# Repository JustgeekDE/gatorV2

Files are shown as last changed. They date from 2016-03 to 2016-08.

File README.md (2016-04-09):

# Gator
Gator started as a small project to built a set of multipurpose, breadboard friendly TTL gates. It has since morphed into the endeavour to create a complete CPU built out of only discrete NPN transistors, resistors and capacitors.  
It also serves as a test bed for a few techniques to improve the hardware development process.

A 1-Bit full adder
(Above is a 1-bit full adder)

## Errata
- The current instruction set is missing any way to read a memory address from a register. This makes pointers, array iterations and linked list impossible or at least very hard.

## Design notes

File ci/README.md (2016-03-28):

# gator

A continuous delivery pipeline for FIXME

## Usage

* `lein run` will start your pipeline with a web-ui listening on port 8080

## Files

* `/`
    * `project.clj` contains dependencies and build configuration for Leiningen

* `/src/gator/`
    * `pipeline.clj` contains your pipeline-definition
    * `steps.clj` contains your custom build-steps
    * `core.clj` contains the `main` function that wires everything together

* `/resources/`
    * `logback.xml` contains a sample log configuration

## References

* for a more detailed example, look at the [example pipeline](https://github.com/flosell/lambdacd/tree/master/src/todopipeline) in the main LambdaCD project

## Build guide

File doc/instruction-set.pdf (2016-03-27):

# Fistful instruction set

## Word length and bus width

The native word length and memory bus width of the fistful CPU is 12-bit. There is no distinction between registers and other memory, all 4096 12-bit address are directly accessible.
Register 4095 is the program counter (PC) and will be automatically incremented after each instruction has been processed.

## Instruction set

Every instruction is a fixed 32-bit wide. The output is always stored in the first operand. The second operand can be either a register address, an immediate value or be ignored (in case of the identity and invert instructions).
The output of the compare operation will always be either 0x000 or 0xFFF.
All instructions can be made conditional through the first 3 bits of the instruction.
Jumps and conditional jumps can be executed by adding or subtracting from the program counter (register 4095) directly. However the program counter will be incremented by one after the instruction, this needs to be accounted for in the jump instruction.

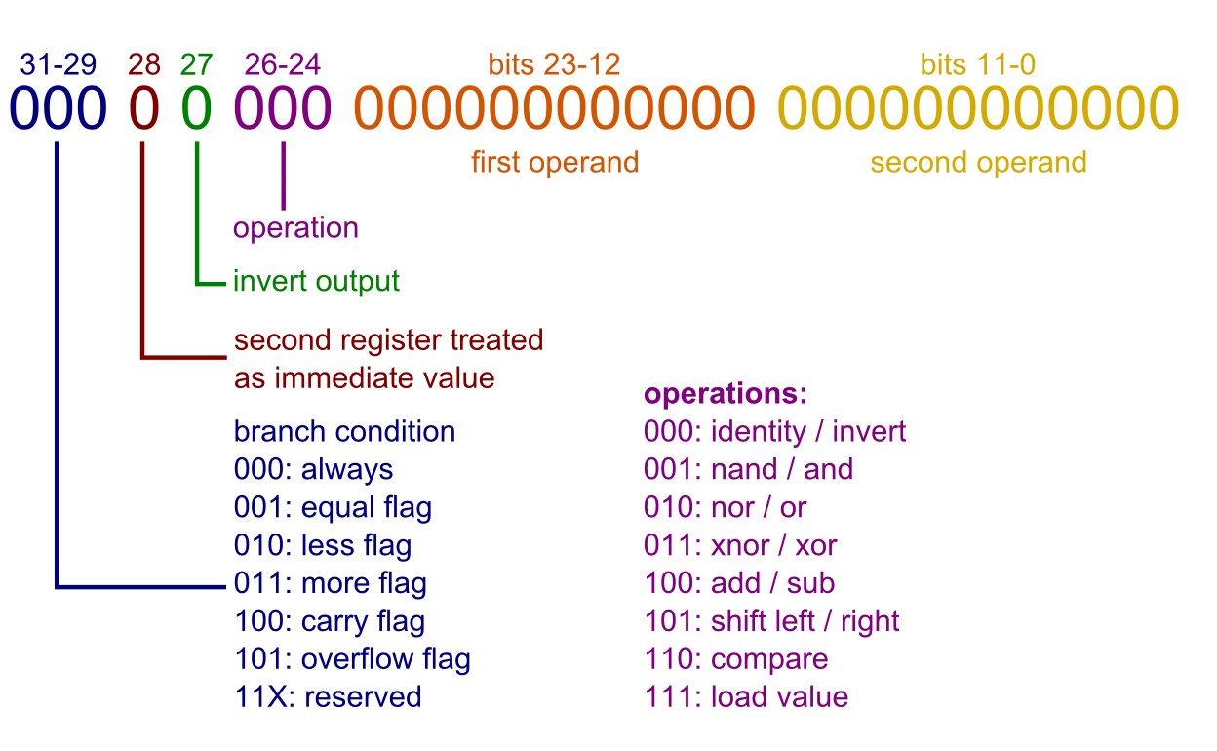
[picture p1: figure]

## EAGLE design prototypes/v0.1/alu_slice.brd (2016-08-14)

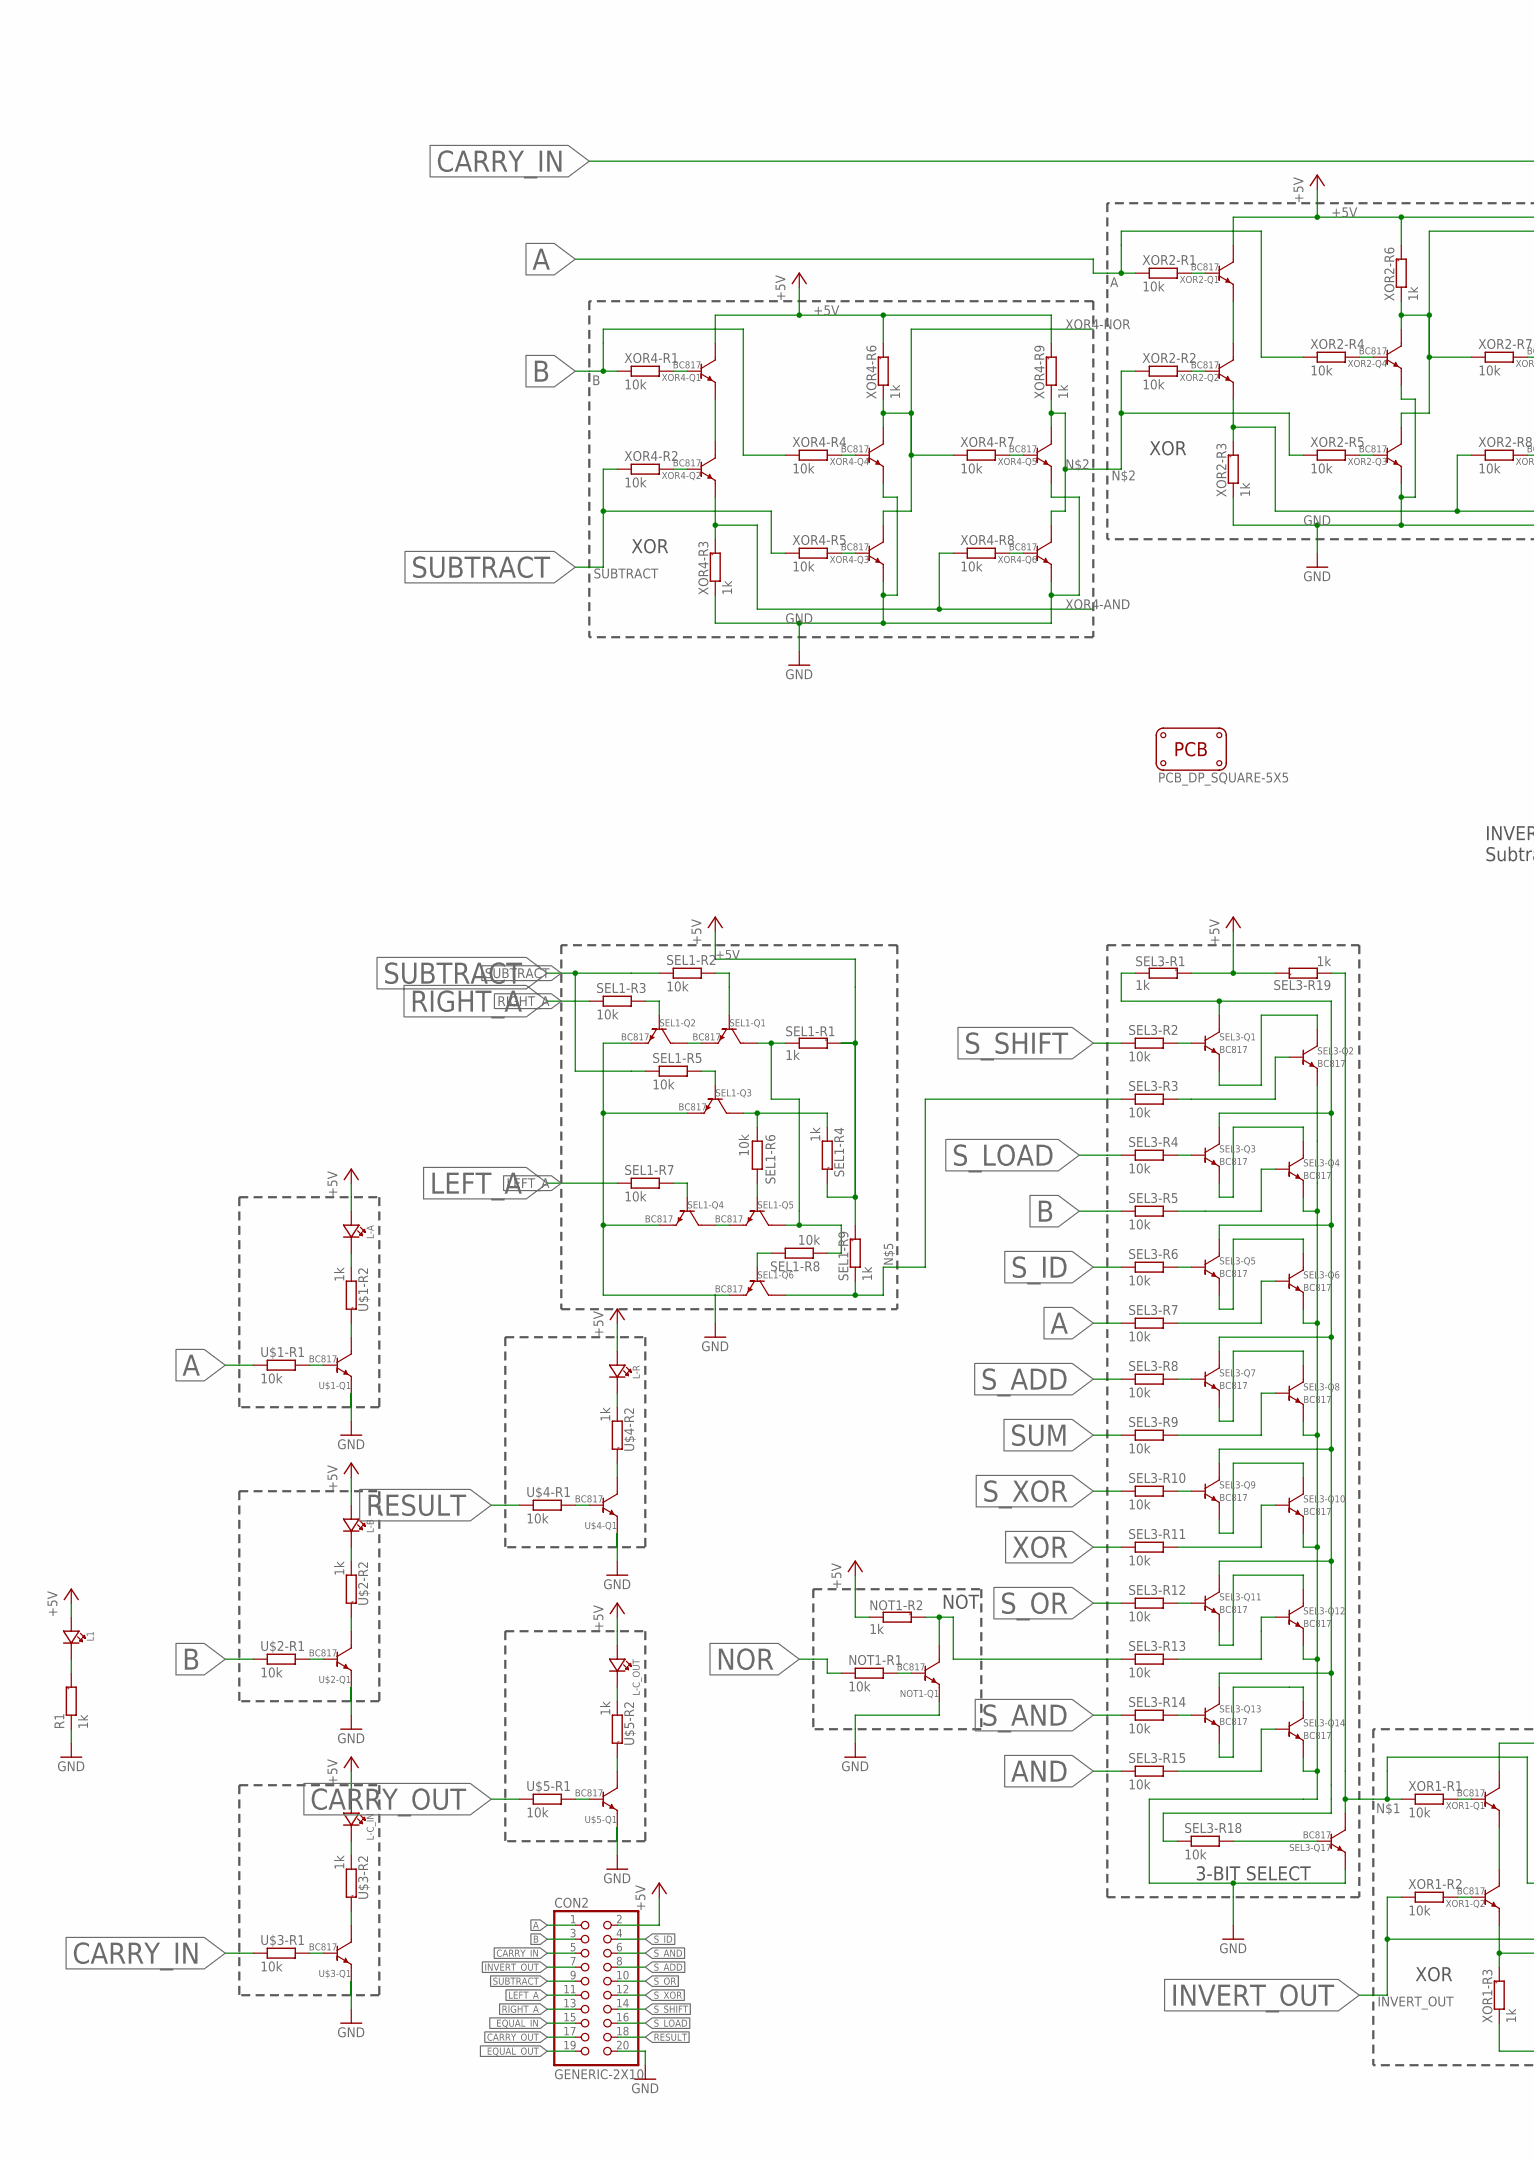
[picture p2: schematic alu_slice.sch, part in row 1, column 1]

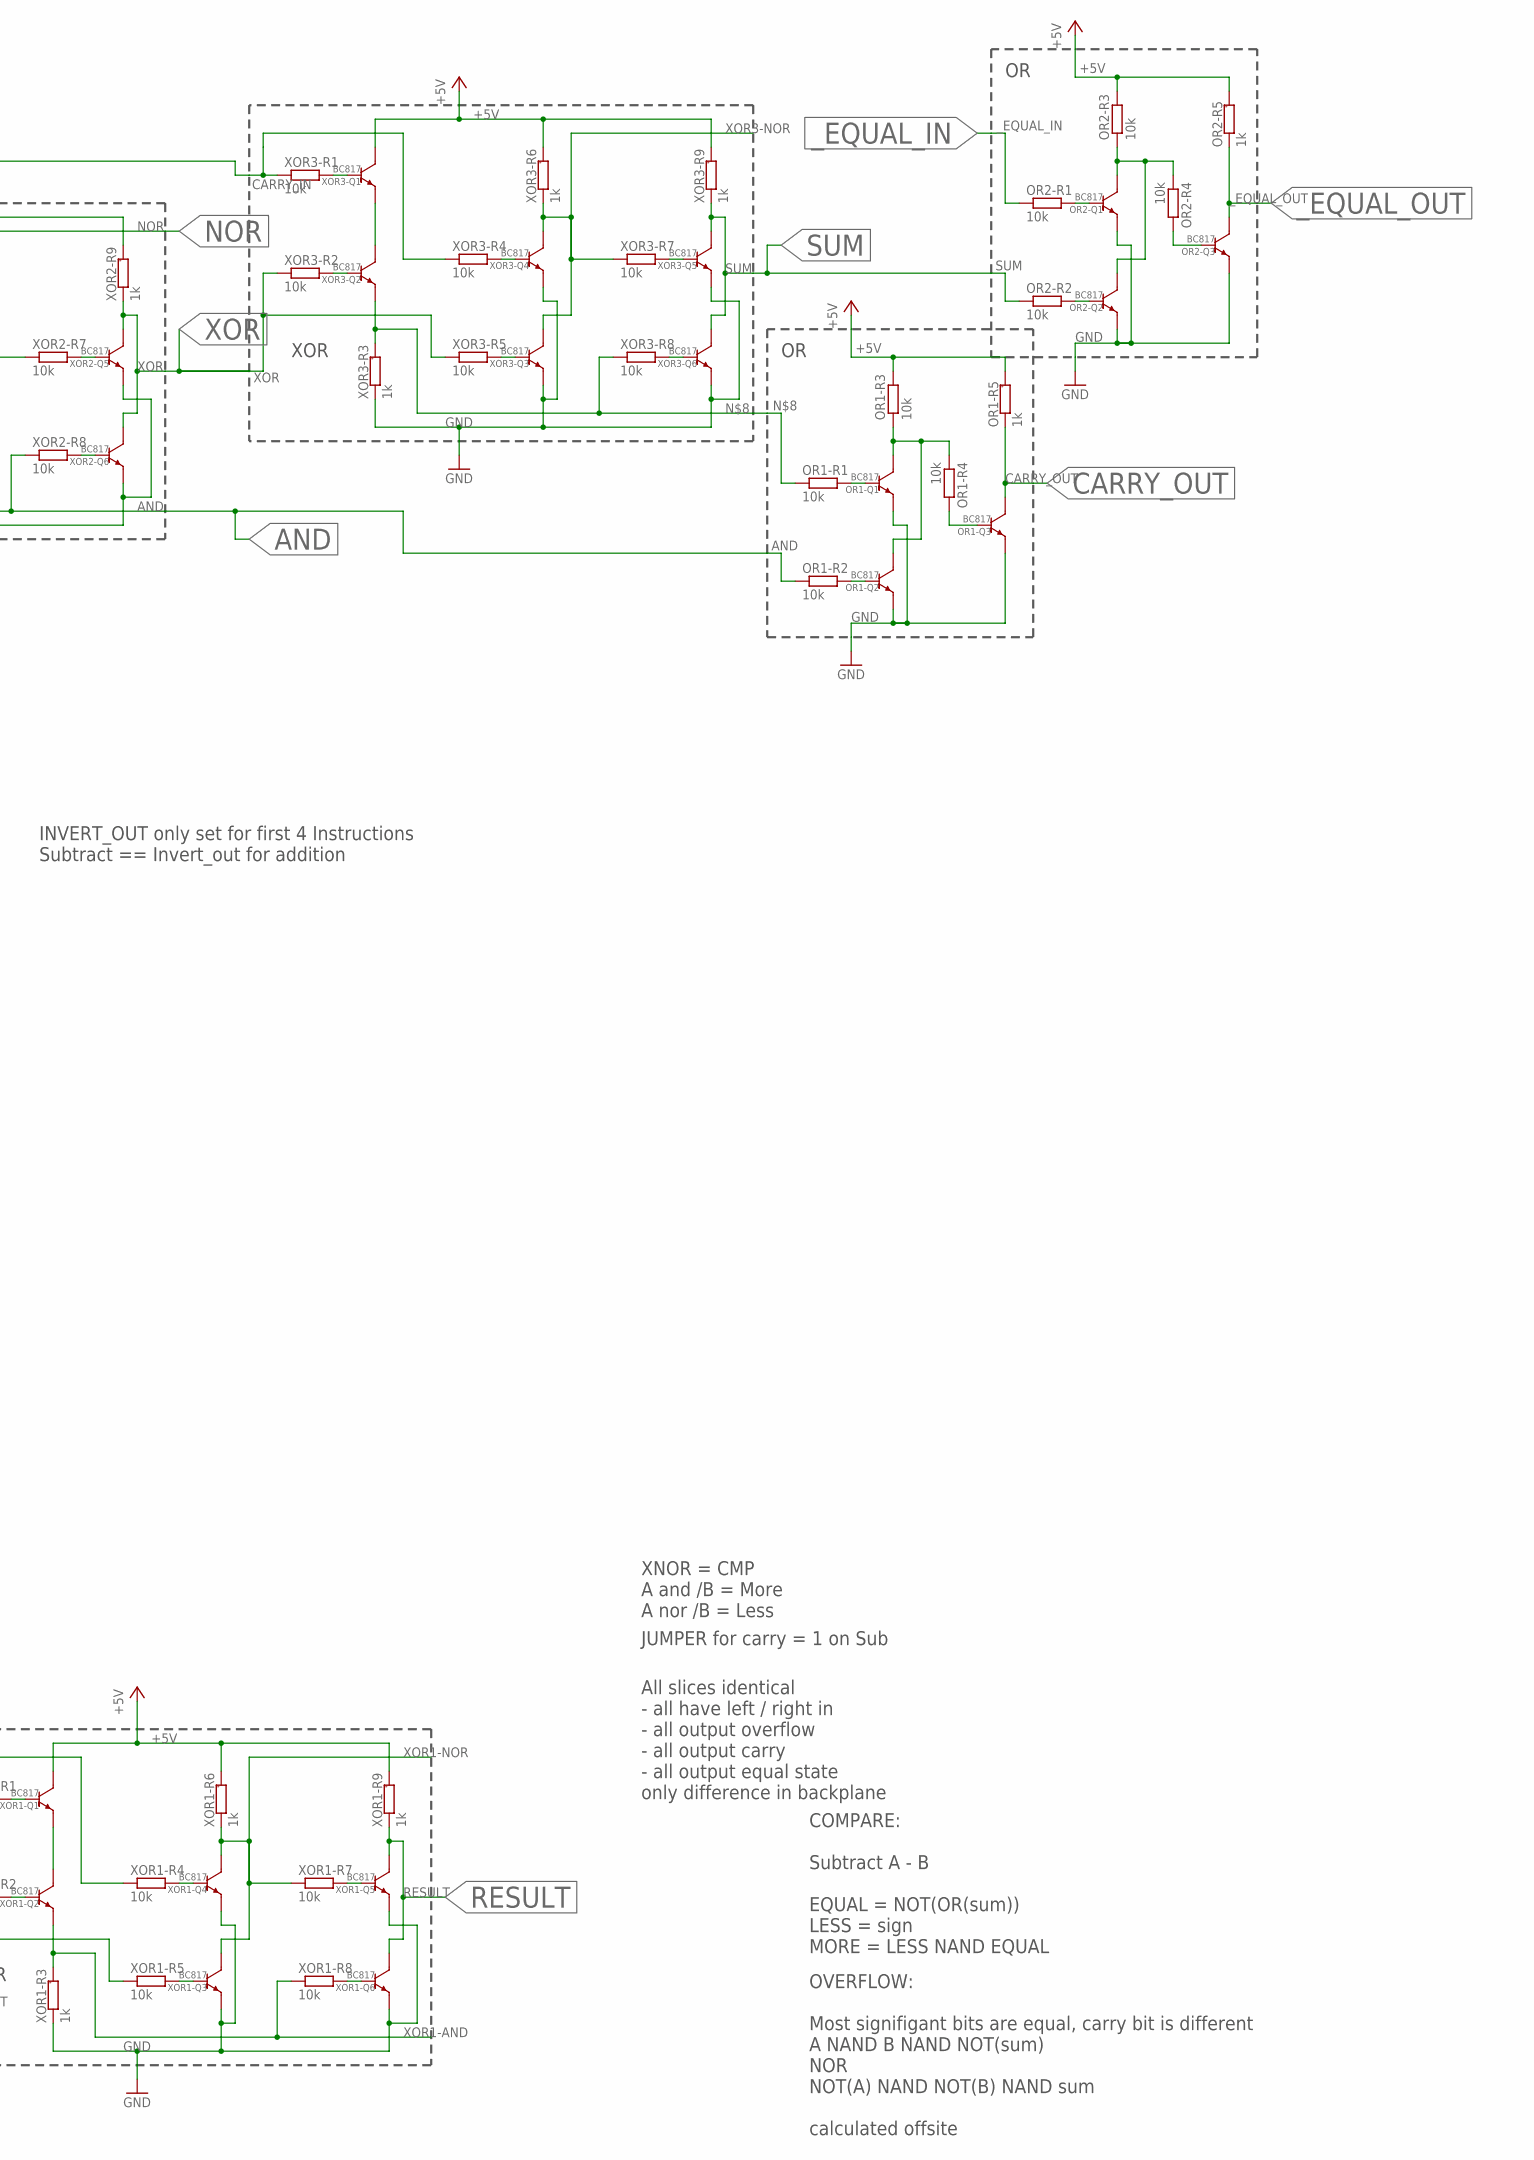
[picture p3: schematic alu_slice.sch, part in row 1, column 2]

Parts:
CON2: GENERIC-2X10; PINHEADER-100MIL-2X10-EDGE
L1: LED0805; CHIPLED_0805
L-A: LED0603; CHIPLED_0603
L-B: LED0603; CHIPLED_0603
L-C_IN: LED0603; CHIPLED_0603
L-C_OUT: LED0603; CHIPLED_0603
L-R: LED0603; CHIPLED_0603
NOT1-Q1: BC817; SOT23
NOT1-R1: 10k; R0603
NOT1-R2: 1k; R0603-MARK
OR1-Q1, OR1-Q2, OR1-Q3, OR2-Q1, OR2-Q2, OR2-Q3: BC817; SOT23
OR1-R1, OR1-R2, OR1-R3, OR1-R4, OR2-R1, OR2-R2, OR2-R3, OR2-R4: 10k; R0603
OR1-R5, OR2-R5: 1k; R0603-MARK
PCB1: PCB_DP_SQUARE-5X5; DP5050_V1
R1: 1k; R0603-MARK
SEL1-Q1, SEL1-Q2, SEL1-Q3, SEL1-Q4, SEL1-Q5, SEL1-Q6, SEL3-Q1, SEL3-Q2, SEL3-Q3, SEL3-Q4, SEL3-Q5, SEL3-Q6, SEL3-Q7, SEL3-Q8, SEL3-Q9, SEL3-Q10, SEL3-Q11, SEL3-Q12, SEL3-Q13, SEL3-Q14, SEL3-Q17: BC817; SOT23
SEL1-R1, SEL1-R4, SEL1-R9, SEL3-R1, SEL3-R19: 1k; R0603-MARK
SEL1-R2, SEL1-R3, SEL1-R5, SEL1-R6, SEL1-R7, SEL1-R8, SEL3-R2, SEL3-R3, SEL3-R4, SEL3-R5, SEL3-R6, SEL3-R7, SEL3-R8, SEL3-R9, SEL3-R10, SEL3-R11, SEL3-R12, SEL3-R13, SEL3-R14, SEL3-R15, SEL3-R18: 10k; R0603
U$1-Q1, U$2-Q1, U$3-Q1, U$4-Q1, U$5-Q1: BC817; SOT23
U$1-R1, U$2-R1, U$3-R1, U$4-R1, U$5-R1: 10k; R0603
U$1-R2, U$2-R2, U$3-R2, U$4-R2, U$5-R2: 1k; R0603-MARK
XOR1-Q1, XOR1-Q2, XOR1-Q3, XOR1-Q4, XOR1-Q5, XOR1-Q6, XOR2-Q1, XOR2-Q2, XOR2-Q3, XOR2-Q4, XOR2-Q5, XOR2-Q6, XOR3-Q1, XOR3-Q2, XOR3-Q3, XOR3-Q4, XOR3-Q5, XOR3-Q6, XOR4-Q1, XOR4-Q2, XOR4-Q3, XOR4-Q4, XOR4-Q5, XOR4-Q6: BC817; SOT23
XOR1-R1, XOR1-R2, XOR1-R4, XOR1-R5, XOR1-R7, XOR1-R8, XOR2-R1, XOR2-R2, XOR2-R4, XOR2-R5, XOR2-R7, XOR2-R8, XOR3-R1, XOR3-R2, XOR3-R4, XOR3-R5, XOR3-R7, XOR3-R8, XOR4-R1, XOR4-R2, XOR4-R4, XOR4-R5, XOR4-R7, XOR4-R8: 10k; R0603
XOR1-R3, XOR1-R6, XOR1-R9, XOR2-R3, XOR2-R6, XOR2-R9, XOR3-R3, XOR3-R6, XOR3-R9, XOR4-R3, XOR4-R6, XOR4-R9: 1k; R0603-MARK

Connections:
+5V: CON2.2, L1.A, L-A.A, L-B.A, L-C_IN.A, L-C_OUT.A, L-R.A, NOT1-R2.1, OR1-R3.2, OR1-R5.2, OR2-R3.2, OR2-R5.2, SEL1-R1.2, SEL1-R4.2, SEL1-R9.2, SEL3-R1.2, SEL3-R19.2, XOR1-Q1.P$3 (COLLECTOR), XOR1-R6.2, XOR1-R9.2, XOR2-Q1.P$3 (COLLECTOR), XOR2-R6.2, XOR2-R9.2, XOR3-Q1.P$3 (COLLECTOR), XOR3-R6.2, XOR3-R9.2, XOR4-Q1.P$3 (COLLECTOR), XOR4-R6.2, XOR4-R9.2
A: CON2.1, SEL3-R7.1, U$1-R1.1, XOR2-R1.1, XOR2-R4.1
AND: OR1-R2.1, SEL3-R15.1, XOR2-Q2.P$2 (EMITTER), XOR2-R3.2, XOR2-R8.1
B: CON2.3, SEL3-R5.1, U$2-R1.1, XOR4-R1.1, XOR4-R4.1
CARRY_IN: CON2.5, U$3-R1.1, XOR3-R1.1, XOR3-R4.1
CARRY_OUT: CON2.17, OR1-Q3.P$3 (COLLECTOR), OR1-R5.1, U$5-R1.1
GND: CON2.20, NOT1-Q1.P$2 (EMITTER), OR1-Q1.P$2 (EMITTER), OR1-Q2.P$2 (EMITTER), OR1-Q3.P$2 (EMITTER), OR2-Q1.P$2 (EMITTER), OR2-Q2.P$2 (EMITTER), OR2-Q3.P$2 (EMITTER), R1.1, SEL1-Q2.P$2 (EMITTER), SEL1-Q3.P$2 (EMITTER), SEL1-Q4.P$2 (EMITTER), SEL1-Q6.P$2 (EMITTER), SEL3-Q2.P$2 (EMITTER), SEL3-Q4.P$2 (EMITTER), SEL3-Q6.P$2 (EMITTER), SEL3-Q8.P$2 (EMITTER), SEL3-Q10.P$2 (EMITTER), SEL3-Q12.P$2 (EMITTER), SEL3-Q14.P$2 (EMITTER), SEL3-Q17.P$2 (EMITTER), U$1-Q1.P$2 (EMITTER), U$2-Q1.P$2 (EMITTER), U$3-Q1.P$2 (EMITTER), U$4-Q1.P$2 (EMITTER), U$5-Q1.P$2 (EMITTER), XOR1-Q3.P$2 (EMITTER), XOR1-Q4.P$2 (EMITTER), XOR1-Q5.P$2 (EMITTER), XOR1-Q6.P$2 (EMITTER), XOR1-R3.1, XOR2-Q3.P$2 (EMITTER), XOR2-Q4.P$2 (EMITTER), XOR2-Q5.P$2 (EMITTER), XOR2-Q6.P$2 (EMITTER), XOR2-R3.1, XOR3-Q3.P$2 (EMITTER), XOR3-Q4.P$2 (EMITTER), XOR3-Q5.P$2 (EMITTER), XOR3-Q6.P$2 (EMITTER), XOR3-R3.1, XOR4-Q3.P$2 (EMITTER), XOR4-Q4.P$2 (EMITTER), XOR4-Q5.P$2 (EMITTER), XOR4-Q6.P$2 (EMITTER), XOR4-R3.1
INVERT_OUT: CON2.7, XOR1-R2.1, XOR1-R5.1
LEFT_A: CON2.11, SEL1-R7.1
unnamed: SEL3-Q17.P$3 (COLLECTOR), SEL3-R19.1, XOR1-R1.1, XOR1-R4.1
unnamed: XOR2-R2.1, XOR2-R5.1, XOR4-Q5.P$3 (COLLECTOR), XOR4-Q6.P$3 (COLLECTOR), XOR4-R9.1
unnamed: NOT1-Q1.P$3 (COLLECTOR), NOT1-R2.2, SEL3-R13.1
unnamed: SEL1-Q6.P$3 (COLLECTOR), SEL1-R9.1, SEL3-R3.1
unnamed: L1.C, R1.2
unnamed: OR1-R1.1, XOR3-Q2.P$2 (EMITTER), XOR3-R3.2, XOR3-R8.1
NOR: NOT1-R1.1, XOR2-Q3.P$3 (COLLECTOR), XOR2-Q4.P$3 (COLLECTOR), XOR2-R6.1, XOR2-R7.1
NOT1-N$14: NOT1-Q1.P$1 (BASE), NOT1-R1.2
OR1-N$7: OR1-Q1.P$1 (BASE), OR1-R1.2
OR1-N$9: OR1-Q2.P$1 (BASE), OR1-R2.2
OR1-N$10: OR1-Q3.P$1 (BASE), OR1-R4.2
OR1-N$11: OR1-Q1.P$3 (COLLECTOR), OR1-Q2.P$3 (COLLECTOR), OR1-R3.1, OR1-R4.1
OR2-N$7: OR2-Q1.P$1 (BASE), OR2-R1.2
OR2-N$9: OR2-Q2.P$1 (BASE), OR2-R2.2
OR2-N$10: OR2-Q3.P$1 (BASE), OR2-R4.2
OR2-N$11: OR2-Q1.P$3 (COLLECTOR), OR2-Q2.P$3 (COLLECTOR), OR2-R3.1, OR2-R4.1
RESULT: CON2.18, U$4-R1.1, XOR1-Q5.P$3 (COLLECTOR), XOR1-Q6.P$3 (COLLECTOR), XOR1-R9.1
RIGHT_A: CON2.13, SEL1-R3.1
SEL1-I-S2: SEL1-Q3.P$3 (COLLECTOR), SEL1-R4.1, SEL1-R6.1
SEL1-N$53: SEL1-Q1.P$1 (BASE), SEL1-R2.2
SEL1-N$55: SEL1-Q2.P$1 (BASE), SEL1-R3.2
SEL1-N$56: SEL1-Q1.P$2 (EMITTER), SEL1-Q2.P$3 (COLLECTOR)
SEL1-N$57: SEL1-Q5.P$1 (BASE), SEL1-R6.2
SEL1-N$58: SEL1-Q4.P$1 (BASE), SEL1-R7.2
SEL1-N$59: SEL1-Q4.P$3 (COLLECTOR), SEL1-Q5.P$2 (EMITTER)
SEL1-N$60: SEL1-Q6.P$1 (BASE), SEL1-R8.2
SEL1-N$62: SEL1-Q3.P$1 (BASE), SEL1-R5.2
SEL1-SEL_INT1: SEL1-Q1.P$3 (COLLECTOR), SEL1-Q5.P$3 (COLLECTOR), SEL1-R1.1, SEL1-R8.1
SEL3-N$27: SEL3-Q1.P$1 (BASE), SEL3-R2.2
SEL3-N$28: SEL3-Q2.P$1 (BASE), SEL3-R3.2
SEL3-N$29: SEL3-Q1.P$2 (EMITTER), SEL3-Q2.P$3 (COLLECTOR)
SEL3-N$32: SEL3-Q3.P$1 (BASE), SEL3-R4.2
SEL3-N$33: SEL3-Q4.P$1 (BASE), SEL3-R5.2
SEL3-N$34: SEL3-Q3.P$2 (EMITTER), SEL3-Q4.P$3 (COLLECTOR)
SEL3-N$35: SEL3-Q5.P$1 (BASE), SEL3-R6.2
SEL3-N$36: SEL3-Q6.P$1 (BASE), SEL3-R7.2
SEL3-N$37: SEL3-Q5.P$2 (EMITTER), SEL3-Q6.P$3 (COLLECTOR)
SEL3-N$38: SEL3-Q7.P$1 (BASE), SEL3-R8.2
SEL3-N$39: SEL3-Q8.P$1 (BASE), SEL3-R9.2
SEL3-N$40: SEL3-Q7.P$2 (EMITTER), SEL3-Q8.P$3 (COLLECTOR)
SEL3-N$41: SEL3-Q9.P$1 (BASE), SEL3-R10.2
SEL3-N$42: SEL3-Q10.P$1 (BASE), SEL3-R11.2
SEL3-N$43: SEL3-Q9.P$2 (EMITTER), SEL3-Q10.P$3 (COLLECTOR)
SEL3-N$44: SEL3-Q11.P$1 (BASE), SEL3-R12.2
SEL3-N$45: SEL3-Q12.P$1 (BASE), SEL3-R13.2
SEL3-N$46: SEL3-Q11.P$2 (EMITTER), SEL3-Q12.P$3 (COLLECTOR)
SEL3-N$47: SEL3-Q13.P$1 (BASE), SEL3-R14.2
SEL3-N$48: SEL3-Q14.P$1 (BASE), SEL3-R15.2
SEL3-N$49: SEL3-Q13.P$2 (EMITTER), SEL3-Q14.P$3 (COLLECTOR)
SEL3-N$54: SEL3-Q17.P$1 (BASE), SEL3-R18.2
SEL3-SEL_INT: SEL3-Q1.P$3 (COLLECTOR), SEL3-Q3.P$3 (COLLECTOR), SEL3-Q5.P$3 (COLLECTOR), SEL3-Q7.P$3 (COLLECTOR), SEL3-Q9.P$3 (COLLECTOR), SEL3-Q11.P$3 (COLLECTOR), SEL3-Q13.P$3 (COLLECTOR), SEL3-R1.1, SEL3-R18.1
SUBTRACT: CON2.9, SEL1-R2.1, SEL1-R5.1, XOR4-R2.1, XOR4-R5.1
SUM: OR2-R2.1, SEL3-R9.1, XOR3-Q5.P$3 (COLLECTOR), XOR3-Q6.P$3 (COLLECTOR), XOR3-R9.1
S_ADD: CON2.8, SEL3-R8.1
S_AND: CON2.6, SEL3-R14.1
S_ID: CON2.4, SEL3-R6.1
S_LOAD: CON2.16, SEL3-R4.1
S_OR: CON2.10, SEL3-R12.1
S_SHIFT: CON2.14, SEL3-R2.1
S_XOR: CON2.12, SEL3-R10.1
U$1-INT: L-A.C, U$1-R2.1
U$1-N$1: U$1-Q1.P$3 (COLLECTOR), U$1-R2.2
U$1-N$16: U$1-Q1.P$1 (BASE), U$1-R1.2
U$2-INT: L-B.C, U$2-R2.1
U$2-N$1: U$2-Q1.P$3 (COLLECTOR), U$2-R2.2
U$2-N$16: U$2-Q1.P$1 (BASE), U$2-R1.2
U$3-INT: L-C_IN.C, U$3-R2.1
U$3-N$1: U$3-Q1.P$3 (COLLECTOR), U$3-R2.2
U$3-N$16: U$3-Q1.P$1 (BASE), U$3-R1.2
U$4-INT: L-R.C, U$4-R2.1
U$4-N$1: U$4-Q1.P$3 (COLLECTOR), U$4-R2.2
U$4-N$16: U$4-Q1.P$1 (BASE), U$4-R1.2
U$5-INT: L-C_OUT.C, U$5-R2.1
U$5-N$1: U$5-Q1.P$3 (COLLECTOR), U$5-R2.2
U$5-N$16: U$5-Q1.P$1 (BASE), U$5-R1.2
XOR: SEL3-R11.1, XOR2-Q5.P$3 (COLLECTOR), XOR2-Q6.P$3 (COLLECTOR), XOR2-R9.1, XOR3-R2.1, XOR3-R5.1
XOR1-AND: XOR1-Q2.P$2 (EMITTER), XOR1-R3.2, XOR1-R8.1
XOR1-N$19: XOR1-Q1.P$2 (EMITTER), XOR1-Q2.P$3 (COLLECTOR)
XOR1-N$21: XOR1-Q1.P$1 (BASE), XOR1-R1.2
XOR1-N$22: XOR1-Q2.P$1 (BASE), XOR1-R2.2
XOR1-N$23: XOR1-Q3.P$1 (BASE), XOR1-R5.2
XOR1-N$24: XOR1-Q4.P$1 (BASE), XOR1-R4.2
XOR1-N$25: XOR1-Q6.P$1 (BASE), XOR1-R8.2
XOR1-N$26: XOR1-Q5.P$1 (BASE), XOR1-R7.2
XOR1-NOR: XOR1-Q3.P$3 (COLLECTOR), XOR1-Q4.P$3 (COLLECTOR), XOR1-R6.1, XOR1-R7.1
XOR2-N$19: XOR2-Q1.P$2 (EMITTER), XOR2-Q2.P$3 (COLLECTOR)
XOR2-N$21: XOR2-Q1.P$1 (BASE), XOR2-R1.2
XOR2-N$22: XOR2-Q2.P$1 (BASE), XOR2-R2.2
XOR2-N$23: XOR2-Q3.P$1 (BASE), XOR2-R5.2
XOR2-N$24: XOR2-Q4.P$1 (BASE), XOR2-R4.2
XOR2-N$25: XOR2-Q6.P$1 (BASE), XOR2-R8.2
XOR2-N$26: XOR2-Q5.P$1 (BASE), XOR2-R7.2
XOR3-N$19: XOR3-Q1.P$2 (EMITTER), XOR3-Q2.P$3 (COLLECTOR)
XOR3-N$21: XOR3-Q1.P$1 (BASE), XOR3-R1.2
XOR3-N$22: XOR3-Q2.P$1 (BASE), XOR3-R2.2
XOR3-N$23: XOR3-Q3.P$1 (BASE), XOR3-R5.2
XOR3-N$24: XOR3-Q4.P$1 (BASE), XOR3-R4.2
XOR3-N$25: XOR3-Q6.P$1 (BASE), XOR3-R8.2
XOR3-N$26: XOR3-Q5.P$1 (BASE), XOR3-R7.2
XOR3-NOR: XOR3-Q3.P$3 (COLLECTOR), XOR3-Q4.P$3 (COLLECTOR), XOR3-R6.1, XOR3-R7.1
XOR4-AND: XOR4-Q2.P$2 (EMITTER), XOR4-R3.2, XOR4-R8.1
XOR4-N$19: XOR4-Q1.P$2 (EMITTER), XOR4-Q2.P$3 (COLLECTOR)
XOR4-N$21: XOR4-Q1.P$1 (BASE), XOR4-R1.2
XOR4-N$22: XOR4-Q2.P$1 (BASE), XOR4-R2.2
XOR4-N$23: XOR4-Q3.P$1 (BASE), XOR4-R5.2
XOR4-N$24: XOR4-Q4.P$1 (BASE), XOR4-R4.2
XOR4-N$25: XOR4-Q6.P$1 (BASE), XOR4-R8.2
XOR4-N$26: XOR4-Q5.P$1 (BASE), XOR4-R7.2
XOR4-NOR: XOR4-Q3.P$3 (COLLECTOR), XOR4-Q4.P$3 (COLLECTOR), XOR4-R6.1, XOR4-R7.1
_EQUAL_IN: CON2.15, OR2-R1.1
_EQUAL_OUT: CON2.19, OR2-Q3.P$3 (COLLECTOR), OR2-R5.1

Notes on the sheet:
XNOR = CMP
A and /B = More A nor /B = Less
JUMPER for carry = 1 on Sub
All slices identical - all have left / right in - all output overflow - all output carry - all output equal state only difference in backplane
COMPARE: Subtract A - B EQUAL = NOT(OR(sum)) LESS = sign MORE = LESS NAND EQUAL
OVERFLOW: Most signifigant bits are equal, carry bit is different A NAND B NAND NOT(sum) NOR NOT(A) NAND NOT(B) NAND sum calculated offsite
INVERT_OUT only set for first 4 Instructions Subtract == Invert_out for addition
3-BIT SELECT
NOT
XOR

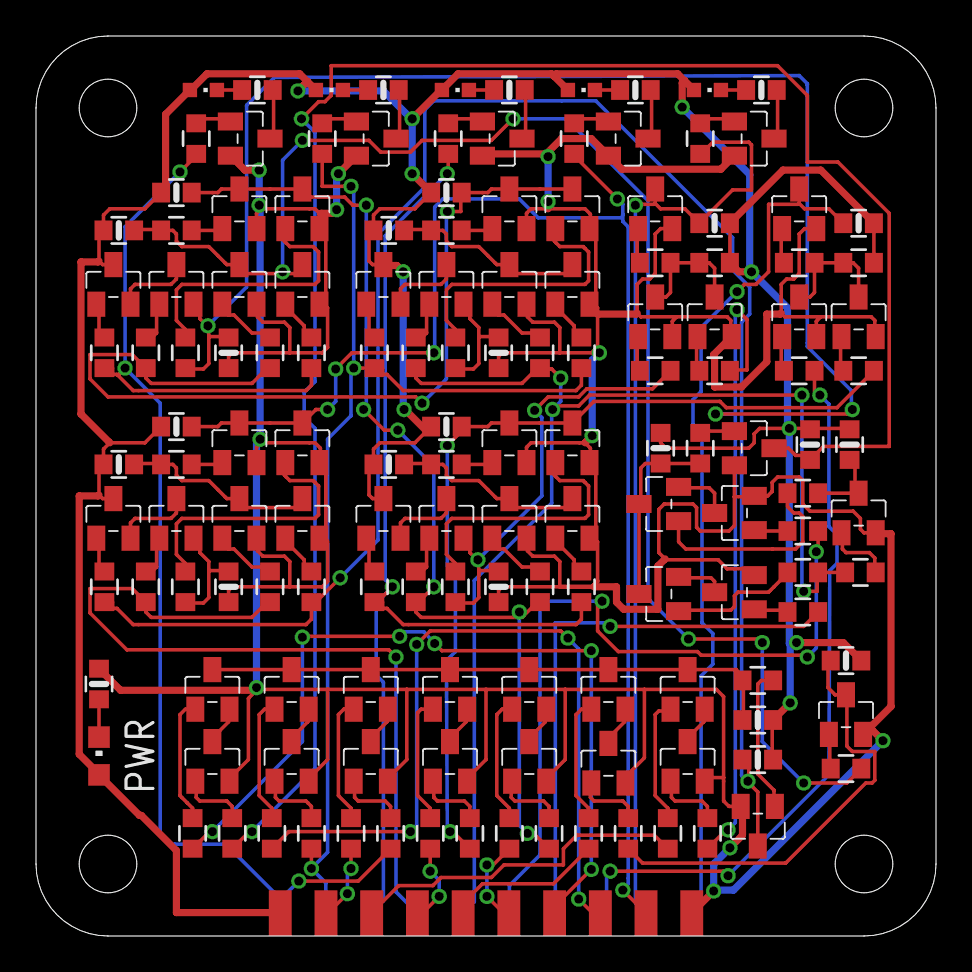
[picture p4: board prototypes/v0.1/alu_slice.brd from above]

Board: 2 copper layers, 50.0 x 50.0 mm, 151 parts (1 on the bottom side), 120 nets.

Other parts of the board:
U$1: LOGO-JUSTGEEK-XS

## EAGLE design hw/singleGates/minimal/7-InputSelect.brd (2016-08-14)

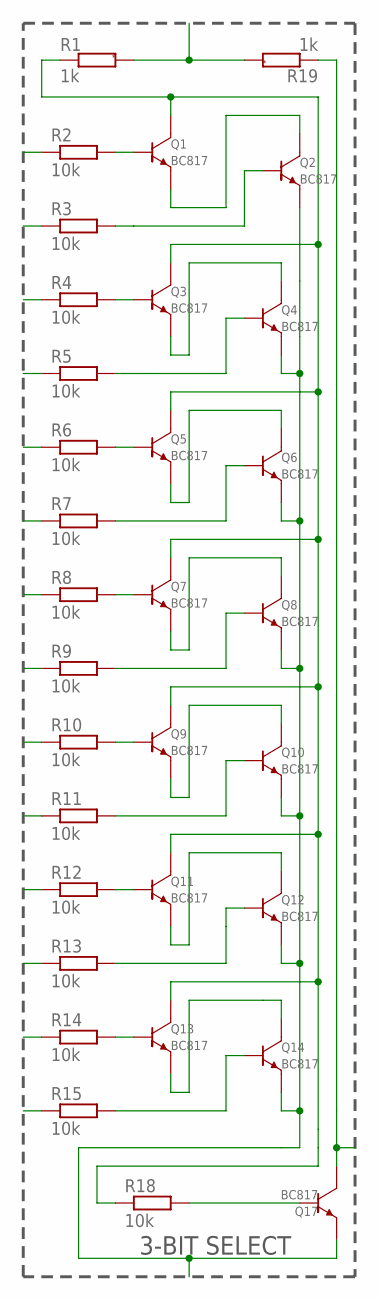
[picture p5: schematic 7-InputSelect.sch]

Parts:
Q1, Q2, Q3, Q4, Q5, Q6, Q7, Q8, Q9, Q10, Q11, Q12, Q13, Q14, Q17: BC817; SOT23
R1, R19: 1k; R0603-MARK
R2, R3, R4, R5, R6, R7, R8, R9, R10, R11, R12, R13, R14, R15, R18: 10k; R0603

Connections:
I1: R3.1
I2: R5.1
I3: R7.1
I4: R9.1
I5: R11.1
I6: R13.1
I7: R15.1
unnamed: Q1.P$1 (BASE), R2.2
unnamed: Q2.P$1 (BASE), R3.2
unnamed: Q1.P$2 (EMITTER), Q2.P$3 (COLLECTOR)
unnamed: Q3.P$1 (BASE), R4.2
unnamed: Q4.P$1 (BASE), R5.2
unnamed: Q3.P$2 (EMITTER), Q4.P$3 (COLLECTOR)
unnamed: Q5.P$1 (BASE), R6.2
unnamed: Q6.P$1 (BASE), R7.2
unnamed: Q5.P$2 (EMITTER), Q6.P$3 (COLLECTOR)
unnamed: Q7.P$1 (BASE), R8.2
unnamed: Q8.P$1 (BASE), R9.2
unnamed: Q7.P$2 (EMITTER), Q8.P$3 (COLLECTOR)
unnamed: Q9.P$1 (BASE), R10.2
unnamed: Q10.P$1 (BASE), R11.2
unnamed: Q9.P$2 (EMITTER), Q10.P$3 (COLLECTOR)
unnamed: Q11.P$1 (BASE), R12.2
unnamed: Q12.P$1 (BASE), R13.2
unnamed: Q11.P$2 (EMITTER), Q12.P$3 (COLLECTOR)
unnamed: Q13.P$1 (BASE), R14.2
unnamed: Q14.P$1 (BASE), R15.2
unnamed: Q13.P$2 (EMITTER), Q14.P$3 (COLLECTOR)
unnamed: Q17.P$1 (BASE), R18.2
OUT: Q17.P$3 (COLLECTOR), R19.1
S1: R2.1
S2: R4.1
S3: R6.1
S4: R8.1
S5: R10.1
S6: R12.1
S7: R14.1
SEL_INT: Q1.P$3 (COLLECTOR), Q3.P$3 (COLLECTOR), Q5.P$3 (COLLECTOR), Q7.P$3 (COLLECTOR), Q9.P$3 (COLLECTOR), Q11.P$3 (COLLECTOR), Q13.P$3 (COLLECTOR), R1.1, R18.1
_VN: Q2.P$2 (EMITTER), Q4.P$2 (EMITTER), Q6.P$2 (EMITTER), Q8.P$2 (EMITTER), Q10.P$2 (EMITTER), Q12.P$2 (EMITTER), Q14.P$2 (EMITTER), Q17.P$2 (EMITTER)
_VP: R1.2, R19.2

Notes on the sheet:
3-BIT SELECT

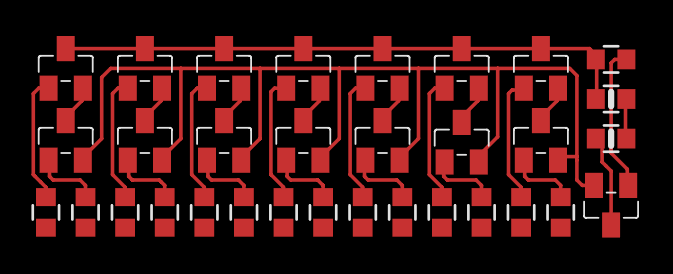
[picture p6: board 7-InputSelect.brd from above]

Board: 2 copper layers, 32 parts (0 on the bottom side), 26 nets.

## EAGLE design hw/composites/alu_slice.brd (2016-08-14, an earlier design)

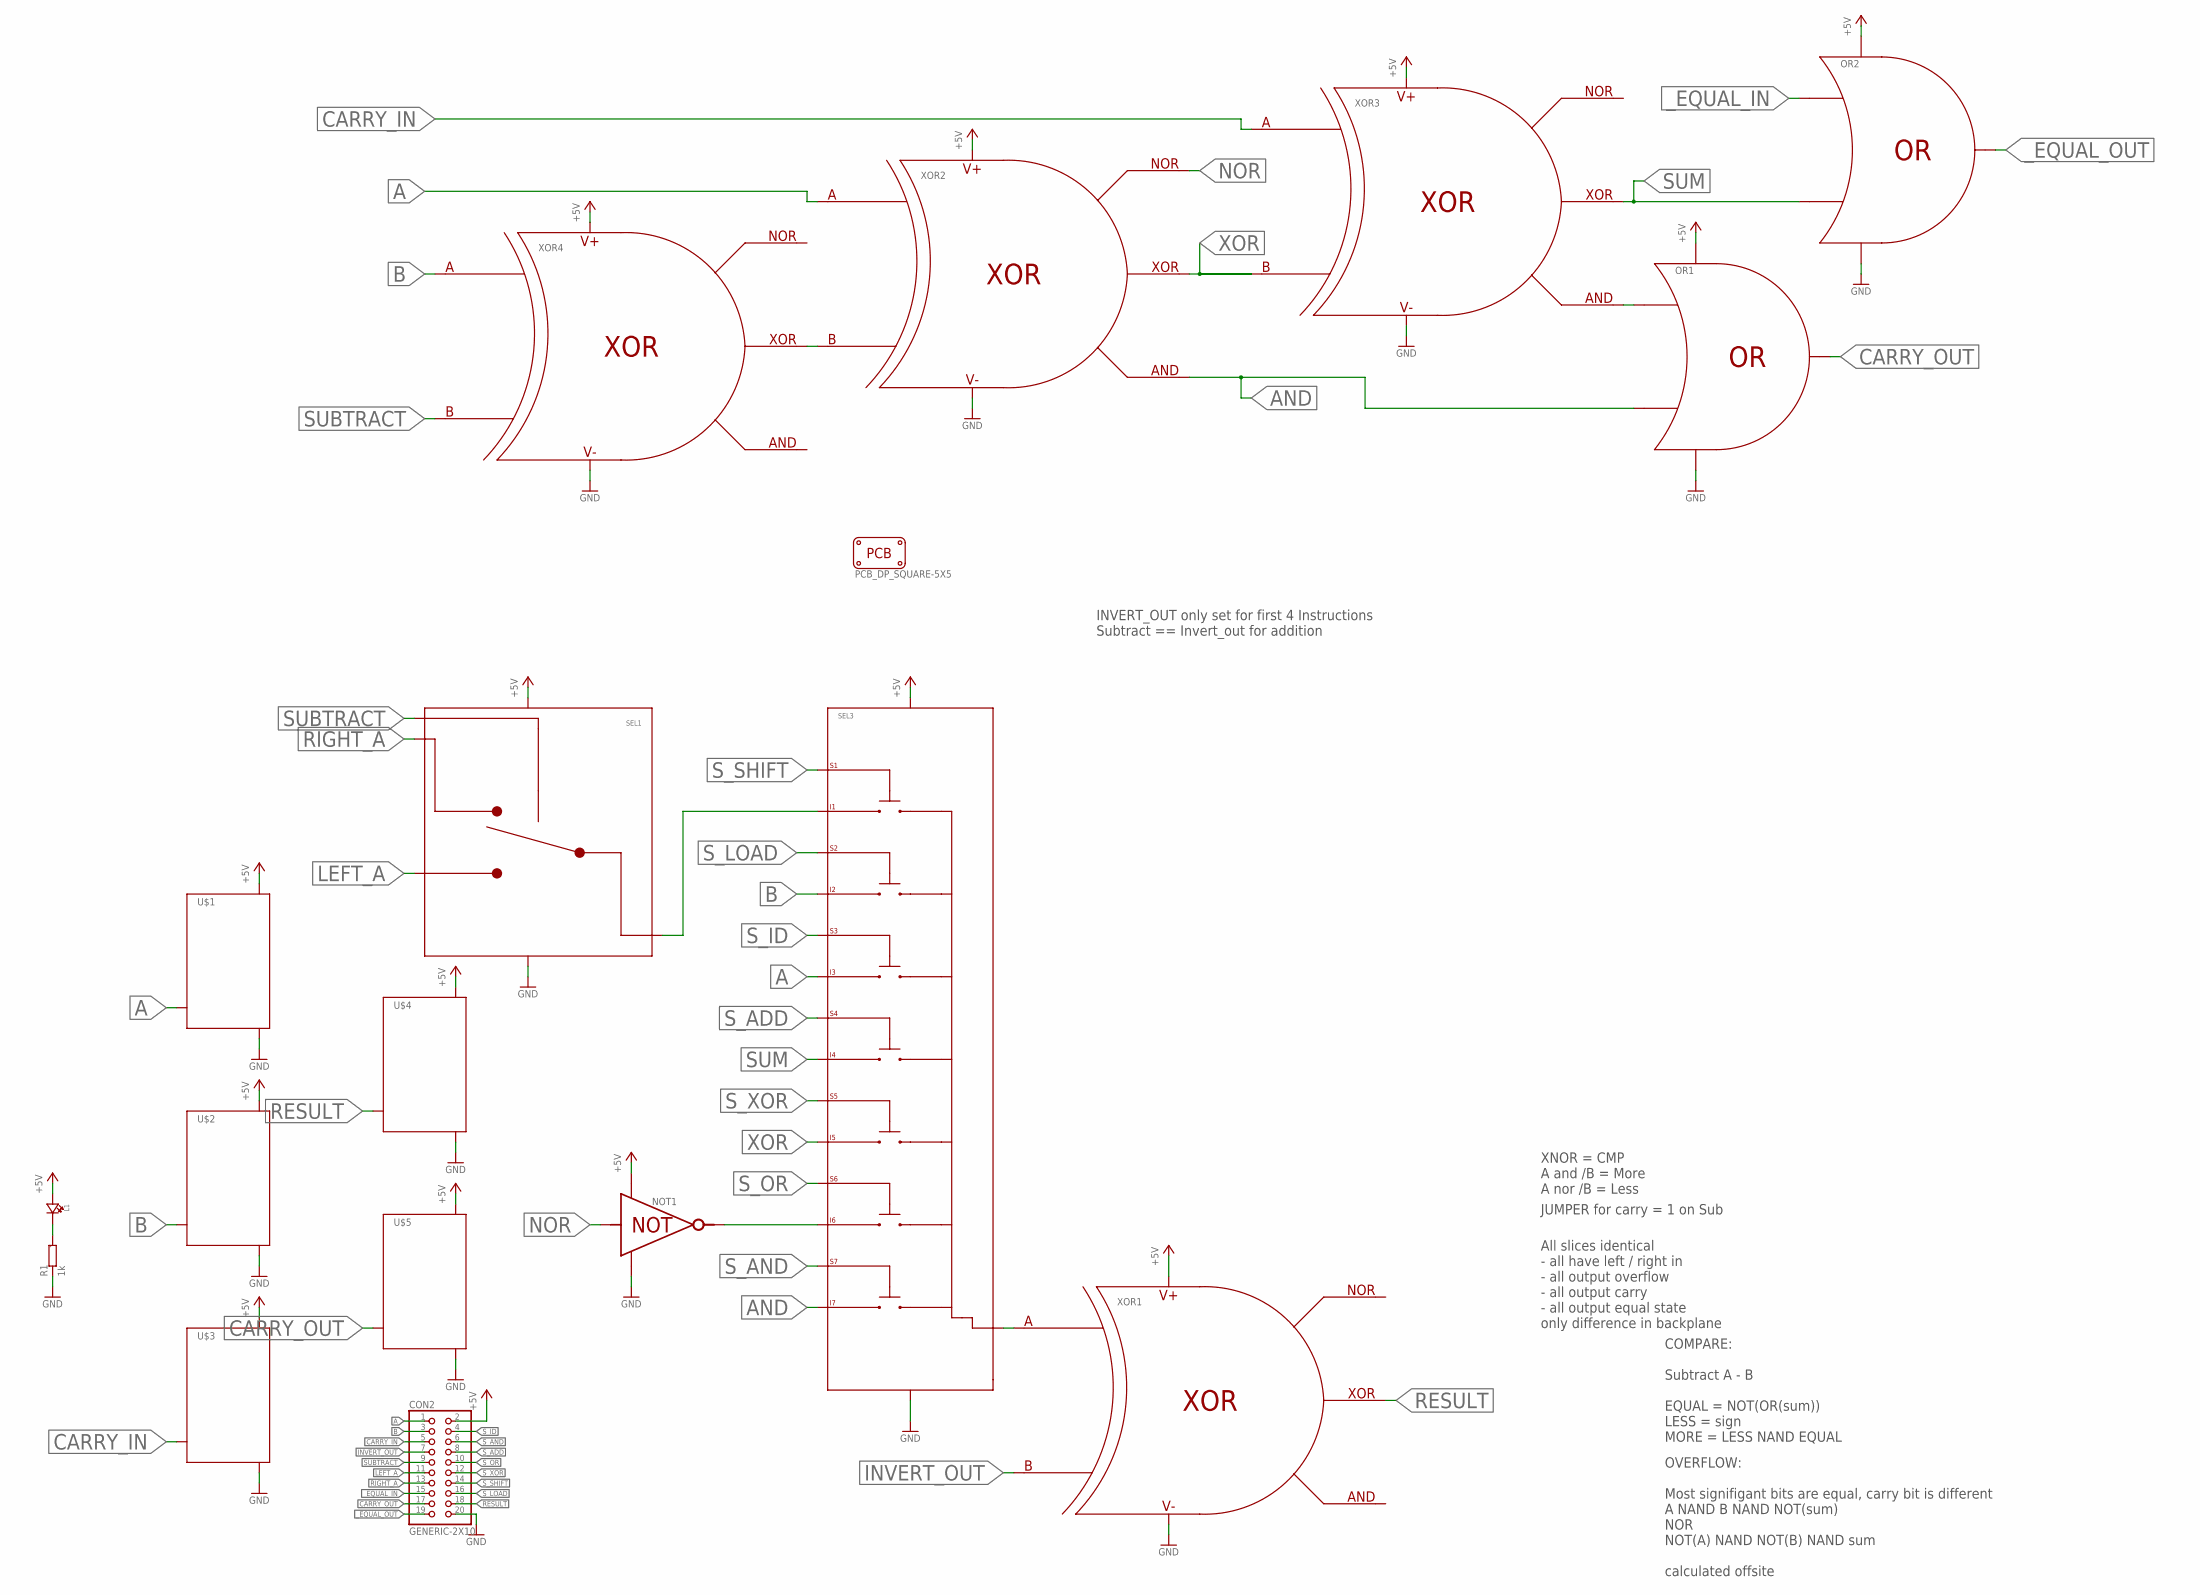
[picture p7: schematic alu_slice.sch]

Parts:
CON2: GENERIC-2X10; PINHEADER-100MIL-2X10-EDGE
L1: LED0805; CHIPLED_0805
NOT1: NOTVERTICAL; NOT-VERTICAL
OR1, OR2: OR
PCB1: PCB_DP_SQUARE-5X5; DP5050_V1
R1: 1k; R0603-MARK
SEL1: 1_BIT_SELECT; SELECTOR-2-LANE-NOMUX
SEL3: 7_VAL_SELECT; SELECTOR-7_BIT-NOMUX
U$1, U$2, U$3, U$4, U$5: LEDDRIVER
XOR1, XOR2, XOR3, XOR4: XOR

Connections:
+5V: CON2.2, L1.A, NOT1._VP, OR1._VP, OR2._VP, SEL1._VP, SEL3._VP, U$1._VP, U$2._VP, U$3._VP, U$4._VP, U$5._VP, XOR1._VP, XOR2._VP, XOR3._VP, XOR4._VP
A: CON2.1, SEL3.I3, U$1.A, XOR2.A
AND: OR1.B, SEL3.I7, XOR2.AND
B: CON2.3, SEL3.I2, U$2.A, XOR4.A
CARRY_IN: CON2.5, U$3.A, XOR3.A
CARRY_OUT: CON2.17, OR1.OR, U$5.A
GND: CON2.20, NOT1._VN, OR1._VN, OR2._VN, R1.1, SEL1._VN, SEL3._VN, U$1._VN, U$2._VN, U$3._VN, U$4._VN, U$5._VN, XOR1._VN, XOR2._VN, XOR3._VN, XOR4._VN
INVERT_OUT: CON2.7, XOR1.B
LEFT_A: CON2.11, SEL1.B
unnamed: SEL3.OUT, XOR1.A
unnamed: XOR2.B, XOR4.XOR
unnamed: NOT1.NOT, SEL3.I6
unnamed: SEL1.OUT, SEL3.I1
unnamed: L1.C, R1.2
unnamed: OR1.A, XOR3.AND
NOR: NOT1.A, XOR2.NOR
RESULT: CON2.18, U$4.A, XOR1.XOR
RIGHT_A: CON2.13, SEL1.A
SUBTRACT: CON2.9, SEL1.SEL, XOR4.B
SUM: OR2.B, SEL3.I4, XOR3.XOR
S_ADD: CON2.8, SEL3.S4
S_AND: CON2.6, SEL3.S7
S_ID: CON2.4, SEL3.S3
S_LOAD: CON2.16, SEL3.S2
S_OR: CON2.10, SEL3.S6
S_SHIFT: CON2.14, SEL3.S1
S_XOR: CON2.12, SEL3.S5
XOR: SEL3.I5, XOR2.XOR, XOR3.B
_EQUAL_IN: CON2.15, OR2.A
_EQUAL_OUT: CON2.19, OR2.OR

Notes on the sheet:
XNOR = CMP
A and /B = More A nor /B = Less
JUMPER for carry = 1 on Sub
All slices identical - all have left / right in - all output overflow - all output carry - all output equal state only difference in backplane
COMPARE: Subtract A - B EQUAL = NOT(OR(sum)) LESS = sign MORE = LESS NAND EQUAL
OVERFLOW: Most signifigant bits are equal, carry bit is different A NAND B NAND NOT(sum) NOR NOT(A) NAND NOT(B) NAND sum calculated offsite
INVERT_OUT only set for first 4 Instructions Subtract == Invert_out for addition

Board: 2 copper layers, 18 parts (0 on the bottom side), 30 nets, no tracks yet.

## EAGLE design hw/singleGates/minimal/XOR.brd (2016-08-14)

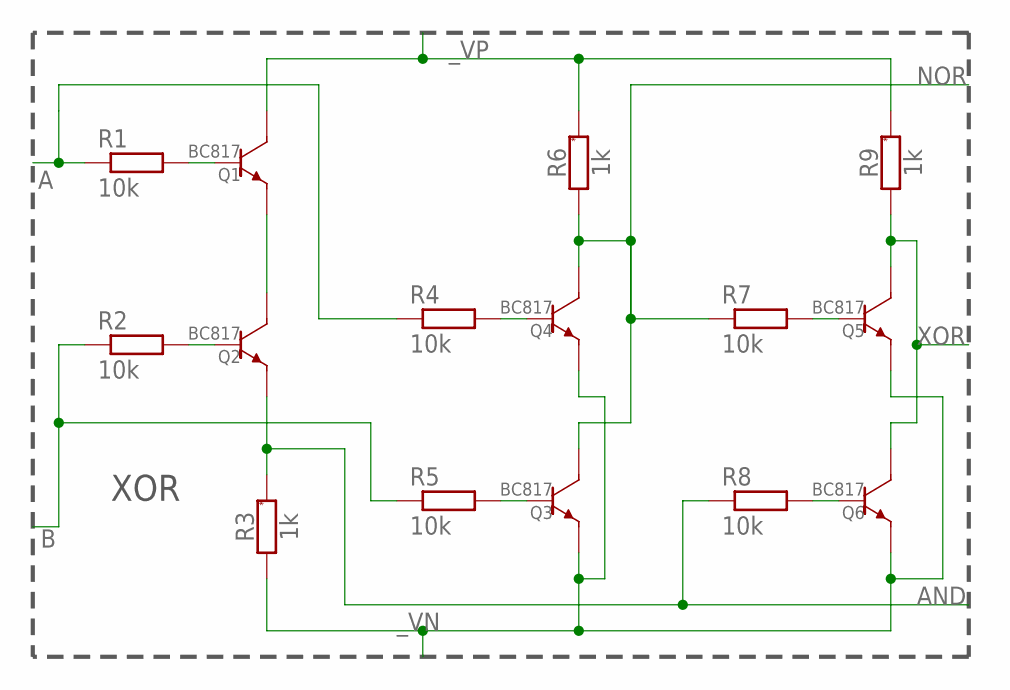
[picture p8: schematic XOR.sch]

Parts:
Q1, Q2, Q3, Q4, Q5, Q6: BC817; SOT23
R1, R2, R4, R5, R7, R8: 10k; R0603
R3, R6, R9: 1k; R0603-MARK

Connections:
A: R1.1, R4.1
AND: Q2.P$2 (EMITTER), R3.2, R8.1
B: R2.1, R5.1
unnamed: Q1.P$2 (EMITTER), Q2.P$3 (COLLECTOR)
unnamed: Q1.P$1 (BASE), R1.2
unnamed: Q2.P$1 (BASE), R2.2
unnamed: Q3.P$1 (BASE), R5.2
unnamed: Q4.P$1 (BASE), R4.2
unnamed: Q6.P$1 (BASE), R8.2
unnamed: Q5.P$1 (BASE), R7.2
NOR: Q3.P$3 (COLLECTOR), Q4.P$3 (COLLECTOR), R6.1, R7.1
XOR: Q5.P$3 (COLLECTOR), Q6.P$3 (COLLECTOR), R9.1
_VN: Q3.P$2 (EMITTER), Q4.P$2 (EMITTER), Q5.P$2 (EMITTER), Q6.P$2 (EMITTER), R3.1
_VP: Q1.P$3 (COLLECTOR), R6.2, R9.2

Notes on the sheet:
XOR

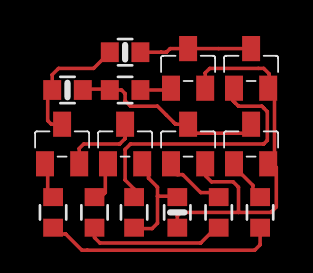
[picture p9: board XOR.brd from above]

Board: 2 copper layers, 15 parts (0 on the bottom side), 14 nets.

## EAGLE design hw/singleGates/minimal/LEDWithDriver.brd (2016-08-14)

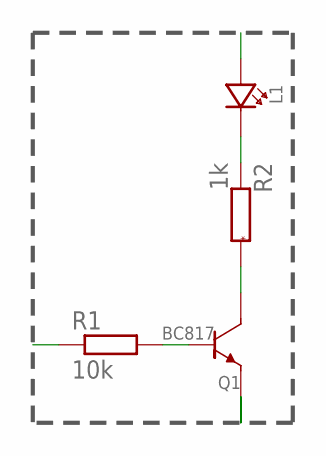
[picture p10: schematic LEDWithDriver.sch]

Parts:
L1: LED0603; CHIPLED_0603
Q1: BC817; SOT23
R1: 10k; R0603
R2: 1k; R0603-MARK

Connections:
A: R1.1
INT: L1.C, R2.1
unnamed: Q1.P$3 (COLLECTOR), R2.2
unnamed: Q1.P$1 (BASE), R1.2
_VN: Q1.P$2 (EMITTER)
_VP: L1.A

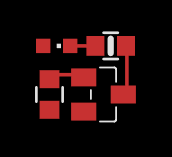
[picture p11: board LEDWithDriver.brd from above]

Board: 2 copper layers, 4 parts (0 on the bottom side), 3 nets.

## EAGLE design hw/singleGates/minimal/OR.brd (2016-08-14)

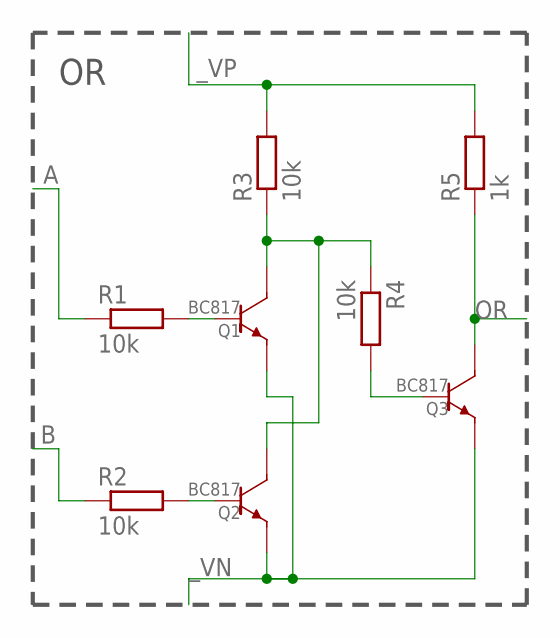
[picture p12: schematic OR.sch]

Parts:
Q1, Q2, Q3: BC817; SOT23
R1, R2, R3, R4: 10k; R0603
R5: 1k; R0603

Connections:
A: R1.1
B: R2.1
unnamed: Q1.P$1 (BASE), R1.2
unnamed: Q2.P$1 (BASE), R2.2
unnamed: Q3.P$1 (BASE), R4.2
unnamed: Q1.P$3 (COLLECTOR), Q2.P$3 (COLLECTOR), R3.1, R4.1
OR: Q3.P$3 (COLLECTOR), R5.1
_VN: Q1.P$2 (EMITTER), Q2.P$2 (EMITTER), Q3.P$2 (EMITTER)
_VP: R3.2, R5.2

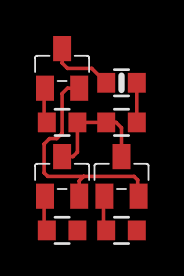
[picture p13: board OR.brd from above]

Board: 2 copper layers, 8 parts (0 on the bottom side), 7 nets.

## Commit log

2016-03-27 Basic documentation
    [data.lines.ods]
2016-03-27 Added first gates
    [AND.brd, AND.sch, NOT-A.brd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]
2016-03-27 Added second version of NOT
    [NOT-B.brd, NOT-B.sch]
2016-03-27 Added OR
    [OR.brd, OR.sch]
2016-03-27 Started changing alu to new format.
    [alu_slice.brd, alu_slice.sch]
2016-03-27 Updated gates to be centered
    [AND.sch, NOT-A.sch, NOT-B.sch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]
2016-03-27 Added NAND
    [NAND.brd, NAND.sch]
2016-03-27 Added 1 bit select
    [1-BitSelect.brd, 1-BitSelect.sch]
2016-03-27 Added 3 bit select
    [3-BitSelect.brd, 3-BitSelect.sch]
2016-03-28 Minor change
    [3-BitSelect.brd]
2016-03-28 Migrated alu to new format
    [alu_slice.brd, alu_slice.sch]
2016-03-28 Started on ALU
    [alu_slice.brd, alu_slice.sch]
2016-03-28 First full test suite
    [AND.brd, AND.sch]
2016-03-28 Changed net names to make spice simulation easier
    [alu_slice.sch]
2016-03-30 Updated supply line names to be more spice compatible
    [1-BitSelect.brd, 1-BitSelect.sch, 3-BitSelect.brd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]
2016-03-31 Fixed logic for switching speed
2016-03-31 XOR tests
    [XOR.brd, XOR.sch]
2016-03-31 Cleaned up name value labels on resistors
    [1-BitSelect.brd, 1-BitSelect.sch, 3-BitSelect.brd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]
2016-04-01 More name/ value fixing
    [AND.brd, XOR.brd, XOR.sch]
2016-04-01 removed unecessary border
    [OR.brd]
2016-04-04 more integration stuff
    [alu_slice.sch]
2016-04-04 Removed dimension border, added tPlace border
    [1-BitSelect.brd]
2016-04-04 Made components to only have connections on 2 sides
    [1-BitSelect.brd, XOR.brd]
2016-04-04 Trying to mimize gates some more
    [3-BitSelect.brd, AND.brd, XOR.brd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]
2016-04-04 Fixing stuff
    [1-BitSelect.brd, alu_slice.brd, alu_slice.sch]
2016-04-05 Fixed silkscreen
    [1-BitSelect.brd]
2016-04-05 Added gate versions without fanout
    [1-BitSelect.brd, 1-BitSelect.sch, 3-BitSelect.brd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]
2016-04-07 reordering board
    [alu_slice.brd, alu_slice.sch]
2016-04-19 Basic cleanups
    [1-BitSelect.sch, NOT-A.sch, XOR.sch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]
2016-04-20 Added more tests for power consumption
2016-04-21 Naming cleanup
    [alu_slice.brd, alu_slice.sch]
2016-04-21 Adds first orgaized integration tests
    [alu_slice.brd, alu_slice.sch]
2016-04-21 fixes some offset and juction issues
    [3-BitSelect.brd, 3-BitSelect.sch, NOT-A.sch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]
2016-04-21 fixes offset issue for 3 bit mux
    [alu_slice.sch]
2016-04-21 Added tests for addition
    [alu_slice.brd, alu_slice.sch]
2016-04-21 Simplified circuit
    [alu_slice.brd, alu_slice.sch]
2016-04-22 Added inversion of output
    [alu_slice.brd, alu_slice.sch]
2016-04-22 adds substraction
    [alu_slice.brd, alu_slice.sch]
2016-04-22 adds support for logical OR
    [alu_slice.brd, alu_slice.sch]
2016-04-22 adds support for bit shifts
    [alu_slice.brd, alu_slice.sch]
2016-04-22 fixes checkstyle
    [alu_slice.sch]
2016-04-22 fixe library
    [1-BitSelect.sch, alu_slice.sch]
2016-04-25 Separated input for shift from inputs for addition
    [alu_slice.brd, alu_slice.sch]
2016-04-25 adds additional tests for offloading of CMP on slice
    [alu_slice.brd, alu_slice.sch]
2016-04-25 cleans up board layout
    [alu_slice.brd, alu_slice.sch]
2016-05-02 Added 7 input selector
    [7-InputSelect.brd, 7-InputSelect.sch]
2016-05-02 changes CMP and ID to use same selector
    [alu_slice.brd, alu_slice.sch]
2016-05-02 adds test to check current draw for all possible inputs
2016-05-02 adds more detailed output to short circuit test
2016-05-09 fixes alignment issues
    [AND.brd, NOT-A.sch, NOT-B.sch]
2016-08-14 Add led output and prepare first alu slice
    [1-BitSelect.brd, 1-BitSelect.sch, 3-BitSelect.brd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]
2016-08-14 Layout for first alu slice prototpye
    [alu_slice.brd, alu_slice.sch]
